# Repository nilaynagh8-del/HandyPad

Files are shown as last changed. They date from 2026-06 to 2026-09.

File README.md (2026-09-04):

# HandyPad

A clean, minimal, handy macropad for times when a 104 keys aren't enough 

*(or just an easier way to copy and paste)* 



---

## Quick Start

1. Hold **BOOT** and plug in your XIAO RP2040.
2. Drop `nilay_macropad_default.uf2` onto the `RPI-RP2` drive.
3. Plug it back in. Watch the little car rev on the OLED.

---

## Features

- **OLED display** to display custom memes or other info
- **Rotary encoder and button** for volume adjustment, scrolling, or whatever you want to map it to!
- **7 keys** to map to the shortcuts you desire
- Every key press (including the encoder push) makes a **car rev on the OLED**

---

## Defaults (if you don't want to change anything):

### Keys:

| Row | Key 1 | Key 2 | Key 3 | Key 4 |
|---|---|---|---|---|
| **Top** | Play/Pause | Previous Track  | Next Track | Rotary Encoder In This Spot|
| **Bottom** | Copy (Ctrl+C) | Paste (Ctrl+V)  | Undo (Ctrl+Z) | Print Screen |

### Encoder:

- **Rotate left** → Volume Down
- **Rotate right** → Volume Up
- **Push** → Mute

---

## What is this?

This is a macropad I built to assist me at my desk. This device can come in handy whether you're designing something in CAD, working on a PCB, gaming, or really anything you would like to use it for.

## How it works and Issues I Faced

The Xiao rp2040 is mounted on the bottom of the PCB along with the diodes. The rest of the components are on the top. The macropad is running **QMK** for the keymaps, screen, and knob. Pretty obvious, but it uses a matrix layout for the switches. 

When I was designing the PCB I wanted to make this macropad as compact as possible with its current hardware which was challenging. I had to reposition the components several times before I was satisfied. I also spent quite some time in CAD designing this case as I wanted to make it as clean as possible. It took me quite some while to find the right shape and and size without making it look awkward.

---

## BOM

- 1x unsoldered Seeed XIAO RP2040
- 7x through-hole 1N4148 Diodes
- 7x MX-Style switches
- 1x EC11 Rotary encoder
- 1x 0.91 inch OLED display *(the pin order is GND-VCC-SCL-SDA, **MAKE SURE YOUR PCB MATCHES**)*
- 7x white blank DSA keycaps
- 6x M3x16mm screws

---

## Renders/Images







---

## Credits

Big shout out to **Hack Club** for giving me the opportunity to make this macropad. I would also like to thank [Logan Peterson](https://github.com/SharKingStudios/SplashPad/tree/main), as I modeled my readme.md after his hackpad's since I was amazed by how well written it was.

---

## Disclaimer

This project is open source. If anything you make out of this does not work or has any issues, I sincerely apologize, but at the end of the day **that's on you.**

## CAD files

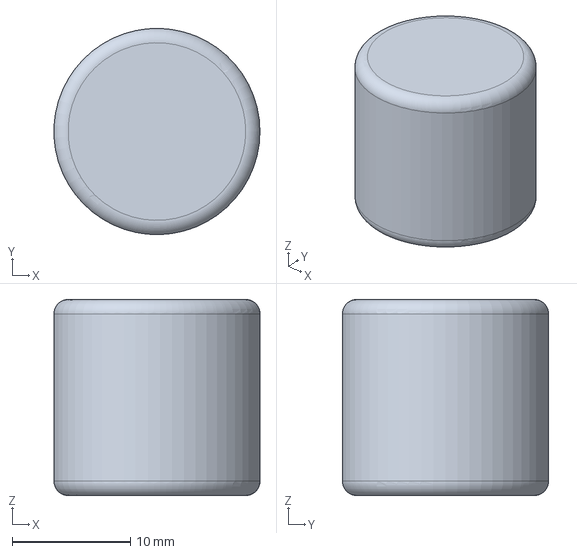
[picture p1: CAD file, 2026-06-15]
Production/Knob (1).step
17.4 x 17.4 x 16.6 mm

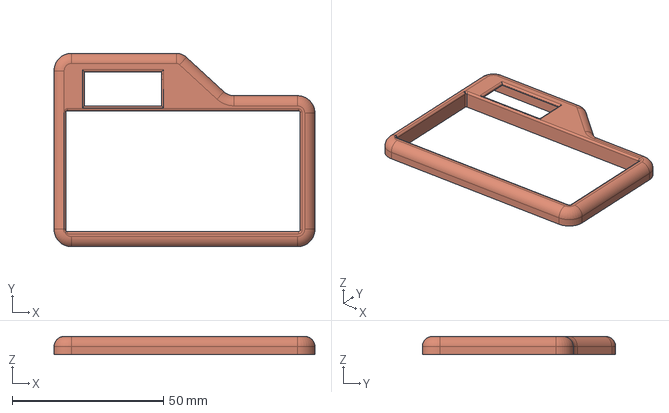
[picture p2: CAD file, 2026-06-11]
Production/Front Case.step
86.4 x 64.0 x 6.00 mm

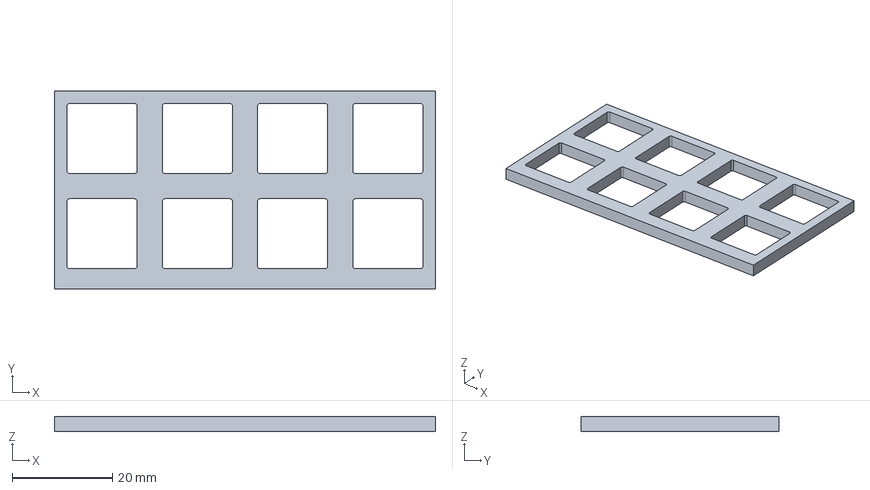
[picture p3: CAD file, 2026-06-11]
Production/Key Switch Spacer.step
76.2 x 39.7 x 3.00 mm

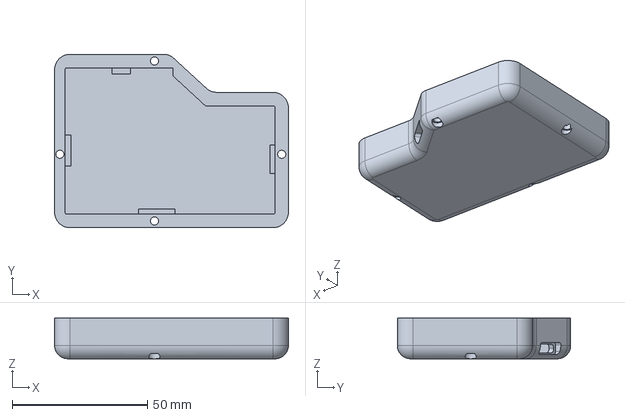
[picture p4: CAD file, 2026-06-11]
Production/Back Case.step
86.4 x 64.0 x 15.0 mm

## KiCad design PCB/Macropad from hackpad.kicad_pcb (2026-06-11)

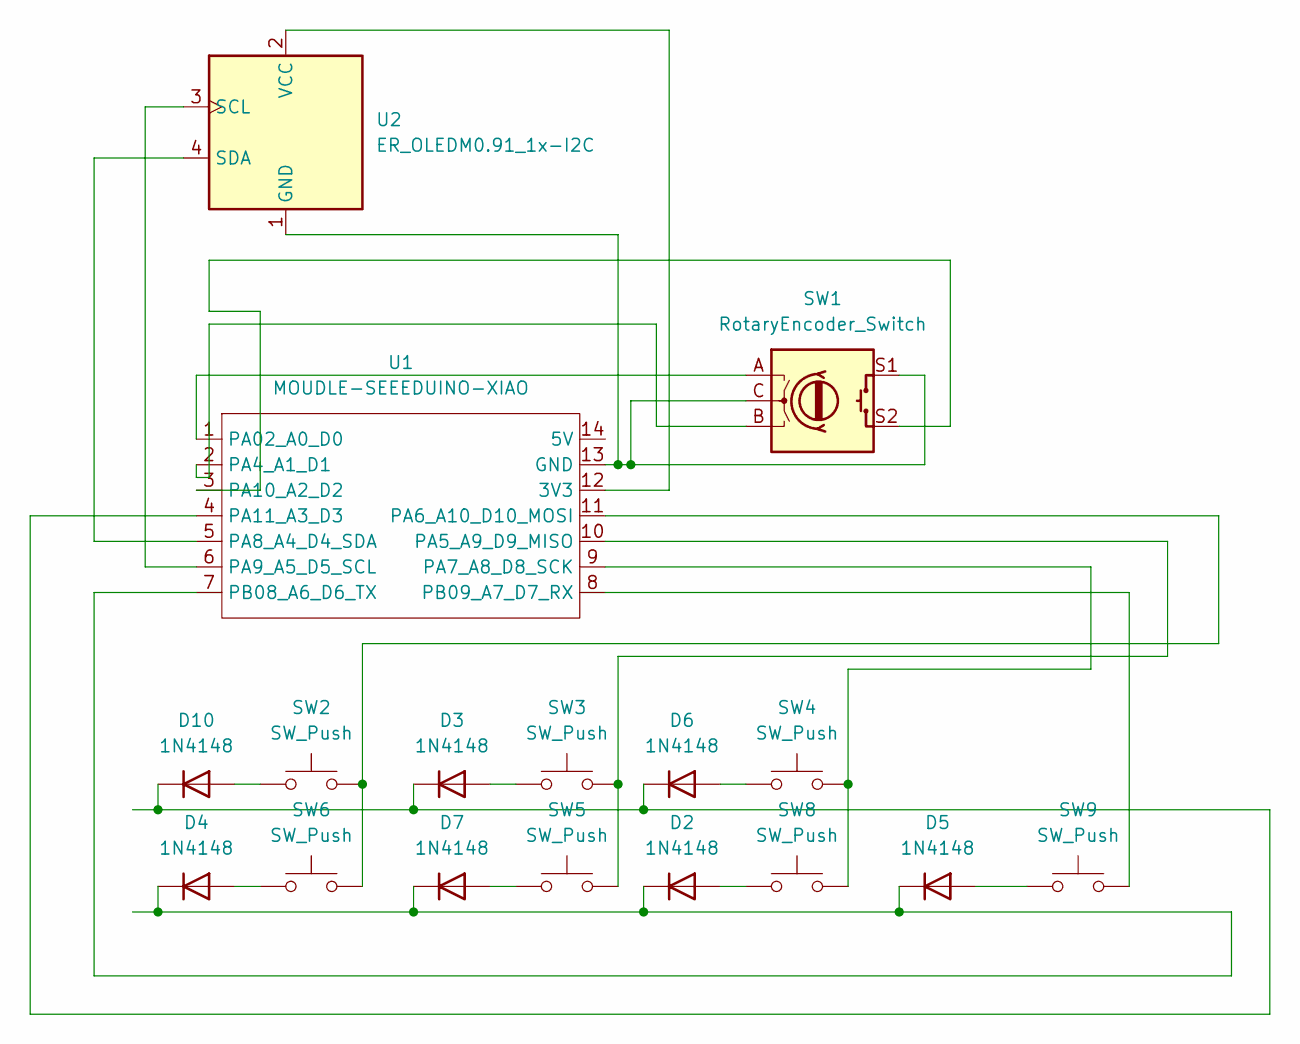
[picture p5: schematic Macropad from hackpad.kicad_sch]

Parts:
D2, D3, D4, D5, D6, D7, D10: 1N4148; D_DO-35_SOD27_P7.62mm_Horizontal
SW1: RotaryEncoder_Switch; RotaryEncoder_Alps_EC11E-Switch_Vertical_H20mm
SW2, SW3, SW4, SW5, SW6, SW8, SW9: SW_Push; SW_Cherry_MX_1.00u_PCB
U1: MOUDLE-SEEEDUINO-XIAO; XIAO-Generic-Hybrid-14P-2.54-21X17.8MM
U2: ER_OLEDM0.91_1x-I2C

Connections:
unnamed: D2.2 (A), SW8.1
unnamed: D2.1 (K), D4.1 (K), D5.1 (K), D7.1 (K), U1.7 (PB08_A6_D6_TX)
unnamed: D3.2 (A), SW3.1
unnamed: D4.2 (A), SW6.1
unnamed: D5.2 (A), SW9.1
unnamed: D6.2 (A), SW4.1
unnamed: D7.2 (A), SW5.1
unnamed: D10.2 (A), SW2.1
unnamed: D3.1 (K), D6.1 (K), D10.1 (K), U1.4 (PA11_A3_D3)
unnamed: U1.12 (3V3), U2.2 (VCC)
unnamed: SW1.C, SW1.S1, U1.13 (GND), U2.1 (GND)
unnamed: SW1.A, U1.1 (PA02_A0_D0)
unnamed: SW1.B, U1.2 (PA4_A1_D1)
unnamed: SW3.2, SW5.2, U1.10 (PA5_A9_D9_MISO)
unnamed: SW2.2, SW6.2, U1.11 (PA6_A10_D10_MOSI)
unnamed: SW4.2, SW8.2, U1.9 (PA7_A8_D8_SCK)
unnamed: U1.5 (PA8_A4_D4_SDA), U2.4 (SDA)
unnamed: U1.6 (PA9_A5_D5_SCL), U2.3 (SCL)
unnamed: SW1.S2, U1.3 (PA10_A2_D2)
unnamed: SW9.2, U1.8 (PB09_A7_D7_RX)

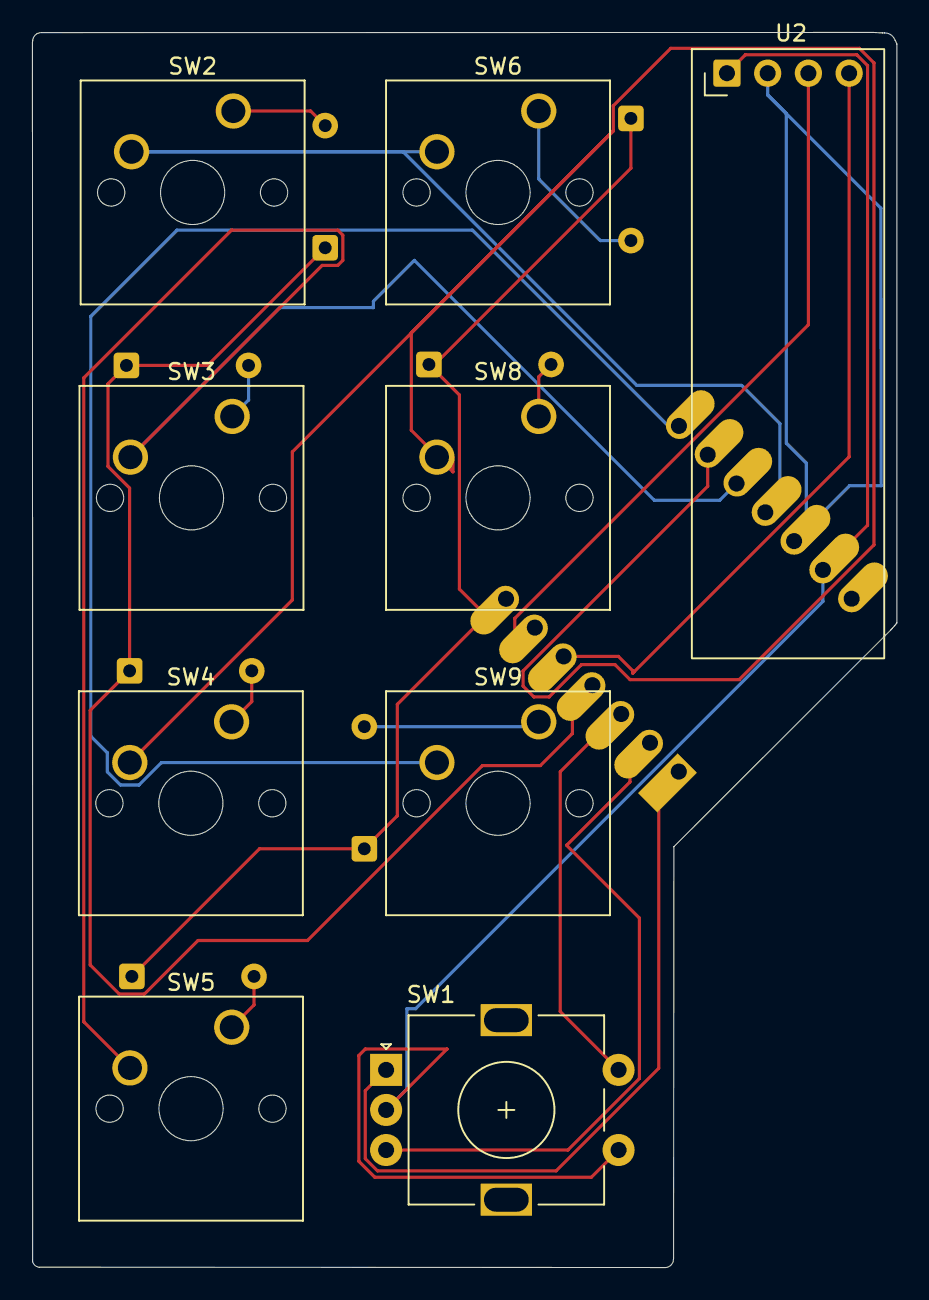
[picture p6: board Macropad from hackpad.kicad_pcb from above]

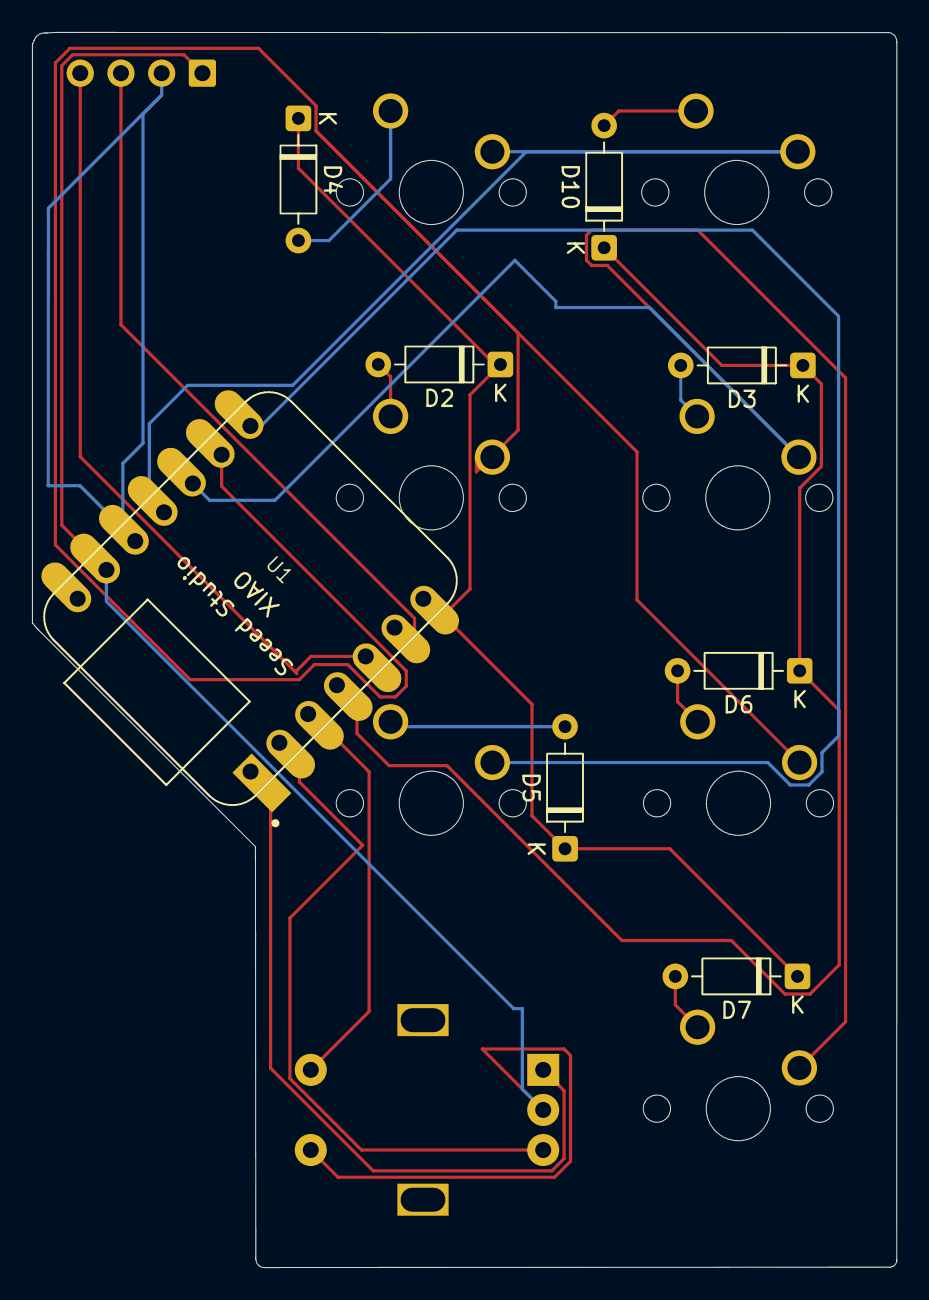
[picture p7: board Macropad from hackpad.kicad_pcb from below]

Board: 2 copper layers, 53.9 x 77.0 mm, 17 parts (8 on the bottom side), 20 nets.

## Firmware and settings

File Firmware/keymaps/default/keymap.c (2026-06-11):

#include QMK_KEYBOARD_H

const uint16_t PROGMEM keymaps[][MATRIX_ROWS][MATRIX_COLS] = {
    [0] = LAYOUT(
        KC_F13, KC_F14, KC_F15,
        KC_F16, KC_F17, KC_F18, KC_F19
    )
};

#if defined(ENCODER_MAP_ENABLE)
const uint16_t PROGMEM encoder_map[][NUM_ENCODERS][NUM_DIRECTIONS] = {
    [0] = { ENCODER_CCW_CW(KC_VOLD, KC_VOLU) }
};
#endif

/* Encoder push button on GP28 (D2), active low, not in matrix */
static bool enc_btn_pressed = false;
static uint32_t enc_btn_timer = 0;

void keyboard_post_init_user(void) {
    gpio_set_pin_input_high(GP28);
}

void matrix_scan_user(void) {
    bool pin_state = !gpio_read_pin(GP28);
    uint32_t now = timer_read32();

    if (pin_state && !enc_btn_pressed && (now - enc_btn_timer > 5)) {
        enc_btn_pressed = true;
        enc_btn_timer   = now;
        register_code(KC_MUTE);
    } else if (!pin_state && enc_btn_pressed && (now - enc_btn_timer > 5)) {
        enc_btn_pressed = false;
        enc_btn_timer   = now;
        unregister_code(KC_MUTE);
    }
}

#ifdef OLED_ENABLE
bool oled_task_user(void) {
    oled_write_ln_P(PSTR("nilay macropad"), false);
    oled_write_ln_P(PSTR("layer 0"), false);
    return false;
}
#endif

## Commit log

2026-06-11 Add new folder structure
    [Back Case.step, Front Case.step, Key Switch Spacer.step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]
2026-06-11 Force remove broken CAD link
2026-06-11 Add valid CAD folder and step file
2026-06-12 Revise README.md with detailed project information
    Updated README.md to provide detailed information about the HandyPad macropad, including features, quick start guide, BOM, and credits.
